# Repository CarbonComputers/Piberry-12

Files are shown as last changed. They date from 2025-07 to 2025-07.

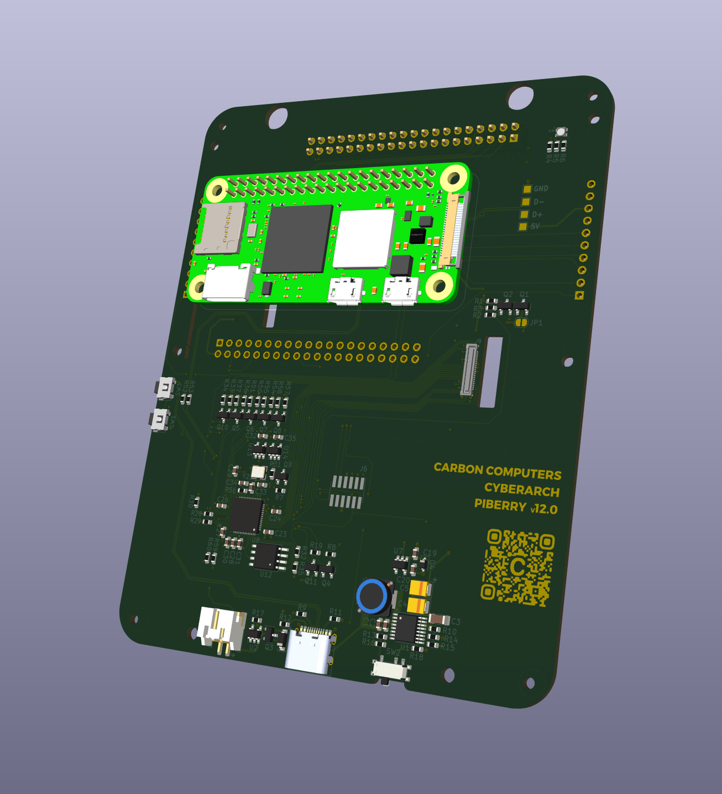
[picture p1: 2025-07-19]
Images/Piberry 12 3D Render bk.png

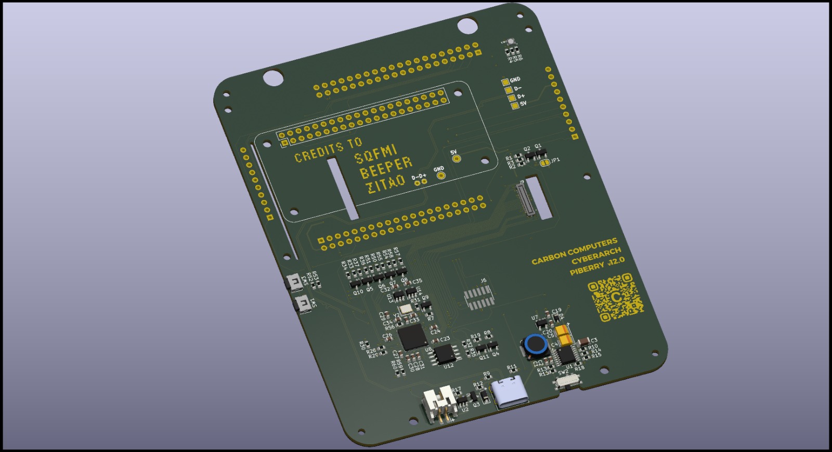
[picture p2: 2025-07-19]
Images/Piberry 12 hd render bk.jpeg

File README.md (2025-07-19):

## PiBerry v12 – Final Iteration

**PiBerry v12** marks the final and most refined revision of the PiBerry handheld Linux terminal. Designed with both form and function in mind, this version brings together the best elements of previous iterations while introducing a more polished aesthetic, improved usability, and support for premium display hardware.

### 🔧 What's New in v12:

* **Refined Aesthetic Design**
  Complete overhaul of the external design for a cleaner, more modern look. Every detail has been revisited to ensure a visually cohesive and ergonomic form factor.
  Keyboard connectivity is simpler as it's driven via USB instead of I2C, you only have to flash the firmware and install the display drivers.

* **HyperPixel 4.0" Display Support**
  Now compatible with the high-resolution **HyperPixel 4.0" touchscreen**, offering a sharper, more responsive interface for your Linux workflows, tools, and custom interfaces, drivers are baked into Pi OS, and many others.
  Waveshare or other 3.5" displays are still compatible, make sure you use the right 3D file

* **Community & Collaboration**
  This final version wouldn’t have been possible without the support and insights of the amazing open-source and hardware community. Special thanks to all contributors, testers, and developers who offered feedback and improvements throughout the PiBerry journey.

### 🔍 Overview:

* Fully integrated handheld Linux device
* Designed around the Raspberry Pi Zero 2W (possibly a CM4 - with a mini carrier)
* Optimized for penetration testing, system diagnostics, portable dev environments, and retro computing/ gaming
* Runs your choice of Linux (Kali, Raspberry Pi OS, etc.)
* Powered by an onboard battery with safe shutdown and charging logic
* Support for keyboards, touch navigation, and peripheral integration with the BBQ20

---

PiBerry v12 is a culmination of passion, learning, and iteration — a celebration of community-powered hardware.

We hope you enjoy building and using it as much as we enjoyed bringing it to life.

Get yours or find out more about the latest builds at [Carbon Computers](https://carboncomputers.us)

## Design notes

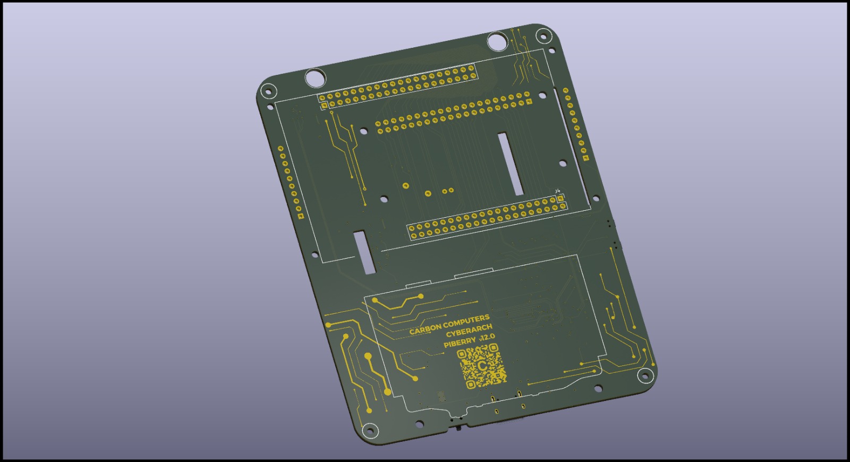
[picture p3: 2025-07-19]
Images/Piberry 12 hd render fr.jpeg

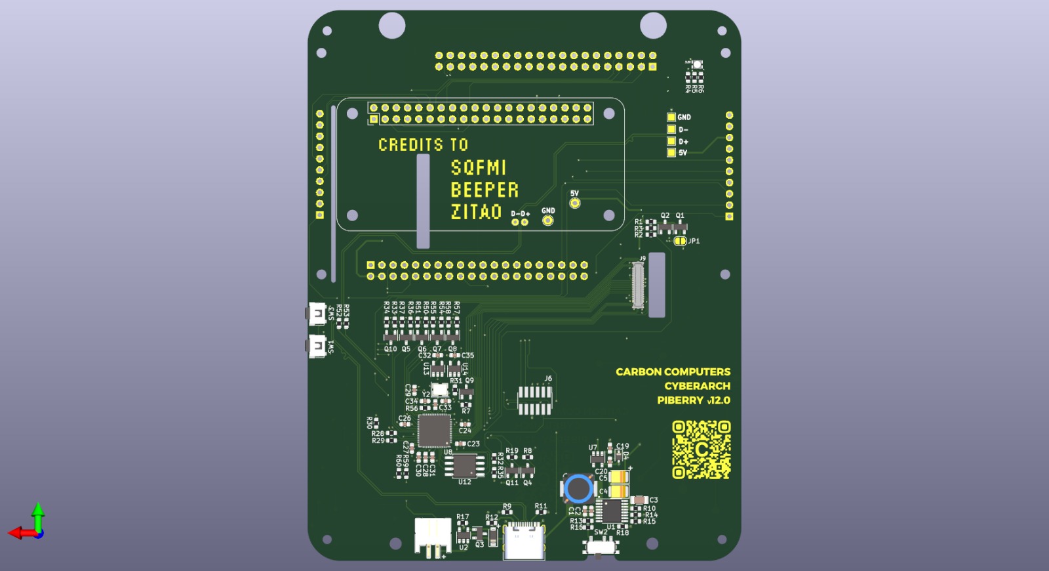
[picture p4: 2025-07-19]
Images/Piberry 12 hd render fl bk.jpeg

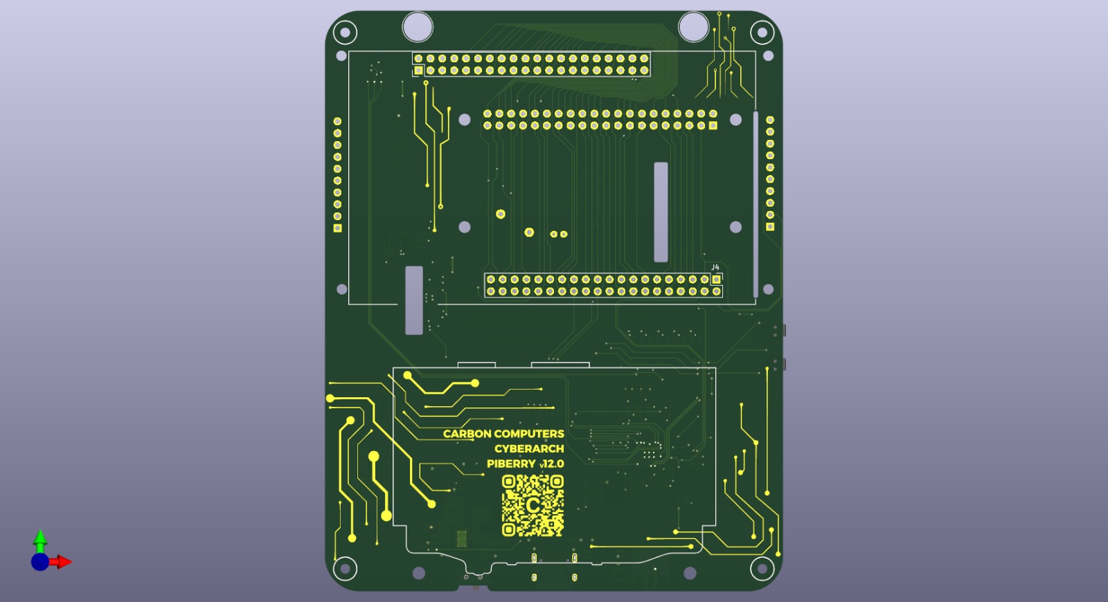
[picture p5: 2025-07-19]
Images/Piberry 12 hd render fl fr.jpeg

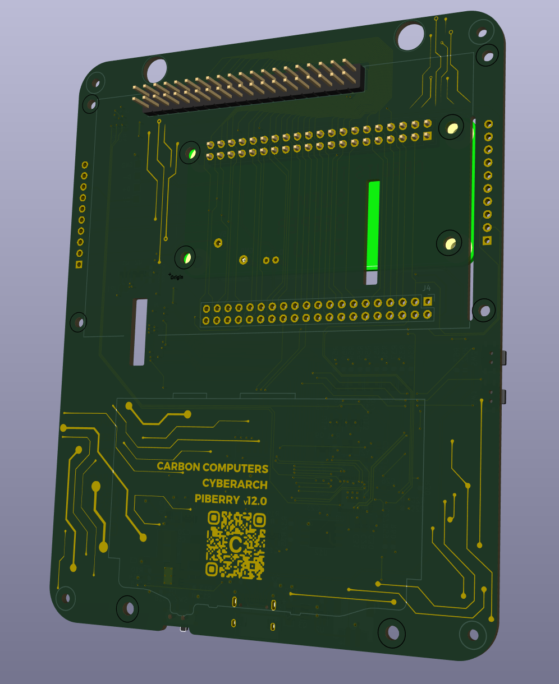
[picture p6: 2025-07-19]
Images/Piberry 12 3D Render fr.png

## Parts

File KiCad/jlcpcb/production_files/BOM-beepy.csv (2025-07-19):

Comment | Designator | Footprint | LCSC
Notification LED | D1 | FM-B2020RGBA-HG | C108793
D_Schottky_Small | D4 | D_SOD-323 | C114023
22uF | C3 | C_1206_3216Metric | C12891
100uF | C4,C5 | CP_EIA-3528-15_AVX-H | C129289
100nF | C2,C23,C24,C25,C26,C27,C29,C30,C32,C35 | C_0603_1608Metric | C14663
1uF | C28,C31 | C_0603_1608Metric | C15849
USB_C_Receptacle_USB2.0 | J7 | USB_C_Receptacle_HRO_TYPE-C-31-M-12 | C165948
RP2040 | U8 | QFN-56-1EP_7x7mm_P0.4mm_EP5.6x5.6mm | C2040
AO3400A | Q10,Q11,Q5,Q6,Q7,Q8,Q9 | SOT-23 | C20917
1K | R32,R56 | R_0603_1608Metric | C21190
100 | R5,R6 | R_0603_1608Metric | C22775
10 | R7 | R_0603_1608Metric | C22859
1M | R15 | R_0603_1608Metric | C22935
220K | R14 | R_0603_1608Metric | C22961
220 | R4 | R_0603_1608Metric | C22962
2M | R10,R13 | R_0603_1608Metric | C22976
330 | R2 | R_0603_1608Metric | C23138
360K | R16 | R_0603_1608Metric | C23146
4.7K | R28,R29 | R_0603_1608Metric | C23162
5.1K | R11,R9 | R_0603_1608Metric | C23186
ME6212C18M5G | U13 | SOT-23-5 | C236669
100K | R12,R18,R59,R60 | R_0603_1608Metric | C25803
10K | R1,R17,R19,R3,R30,R31,R33,R34,R35,R36,R37,R50,R51,R54,R55,R57,R58,R8 | R_0603_1608Metric | C25804
XYDBPCNANF-12MHZ | Y2 | Crystal_SMD_3225-4Pin_3.2x2.5mm | C284155
SI2301 | Q1,Q3 | SOT-23 | C2891731
Battery | J8 | JST_PH_S2B-PH-SM4-TB_1x02-1MP_P2.00mm_Horizontal | C295747
12pF | C33,C34 | C_0603_1608Metric | C38523
27R | R52,R53 | R_0603_1608Metric | C403464
BM20B_0.8_-40DS-0.4V_51_ | J9 | HRS_BM20B_0.8_-40DS-0.4V_51_ | C424543
ME6212C28M5G | U14 | SOT-23-5 | C427596
6.8uH/4A | L1 | L_Bourns_SRP7028A_7.3x6.6mm | C497879
AP2112K-3.3 | U7 | SOT-23-5 | C51118
Header 1 | J1,J3 | PinHeader_1x10_P2.54mm_Vertical | C57369
B5819W | D2 | D_SOD-123 | C64885
TP4054 | U2 | SOT-23-5 | C668215
W25Q32JVSSIQ | U12 | SSOP-8_5.25x5.24mm_P1.27mm | C82344
S8050 | Q2,Q4 | SOT-23 | C916390
ON/OFF | SW2 | SW_SPDT_PCM12 | C963206
SW_DIP_x02 | SW1,SW3 | GT-TC018X | C963235
10uF | C1,C19,C20 | C_0603_1608Metric | C96446
TPS61030 | U1 | HTSSOP-16-1EP_4.4x5mm_P0.65mm_EP3.4x5mm_Mask2.46x2.31mm_ThermalVias | C9842
RPi_GPIO | J2 | PinHeader_2x20_P2.54mm_Vertical

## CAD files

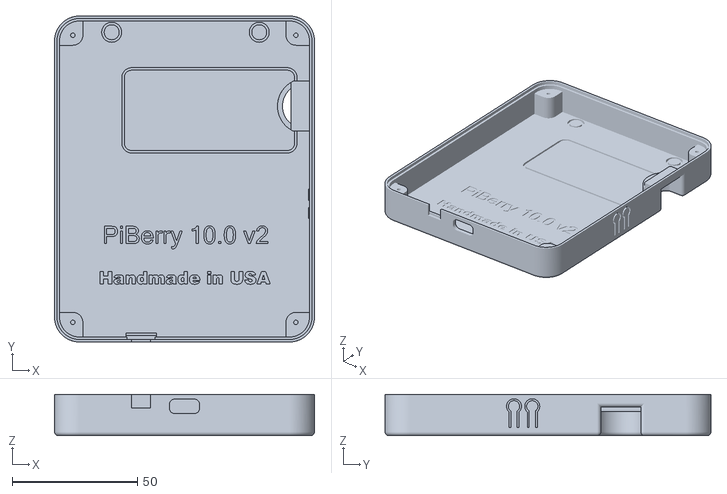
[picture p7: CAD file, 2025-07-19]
3D STL/PiBerry_10.0_v2_retro_STL_STP/PiBerry_10.0_v2_lower_part_rev2.stl
104.0 x 130.4 x 16.5

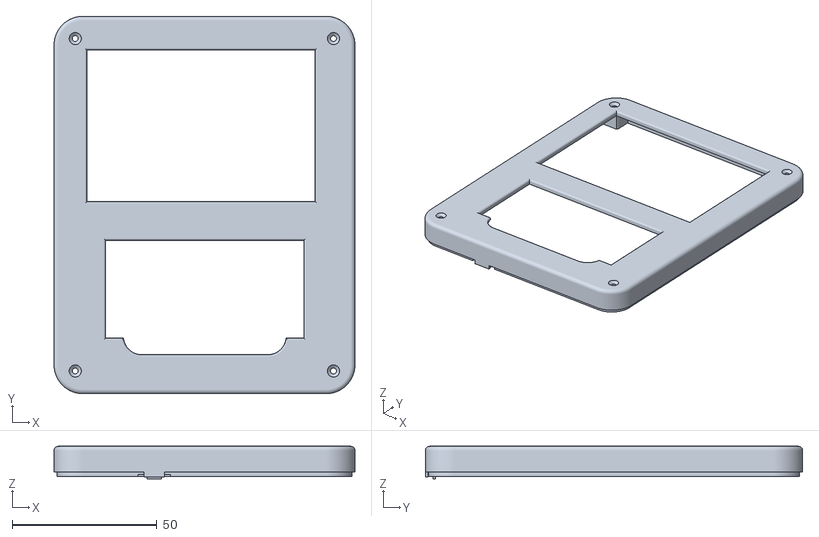
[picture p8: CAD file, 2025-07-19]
3D STL/PiBerry_10.0_v2_simple_STL_STP/PiBerry_10.0_v2_simple_upper_part.stl
104.0 x 130.4 x 11.2

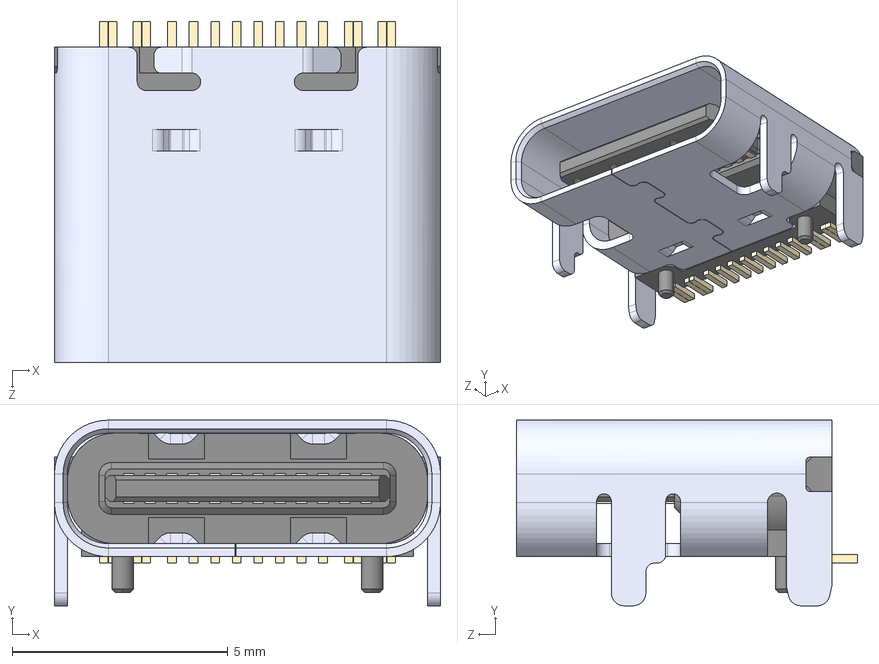
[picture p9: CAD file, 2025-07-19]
KiCad/Step File/TYPE-C-31-M-12--3DModel-STEP-56544.STEP
8.94 x 4.30 x 7.90 mm

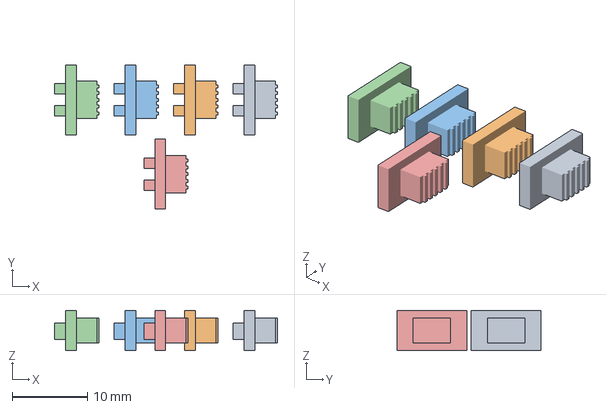
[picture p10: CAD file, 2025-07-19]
3D STL/PiBerry_10.0_v2_retro_STL_STP/sliding_swtich_rev1.3mf
29.7 x 19.2 x 5.35 mm
sliding_swtich_rev1.stl x 5

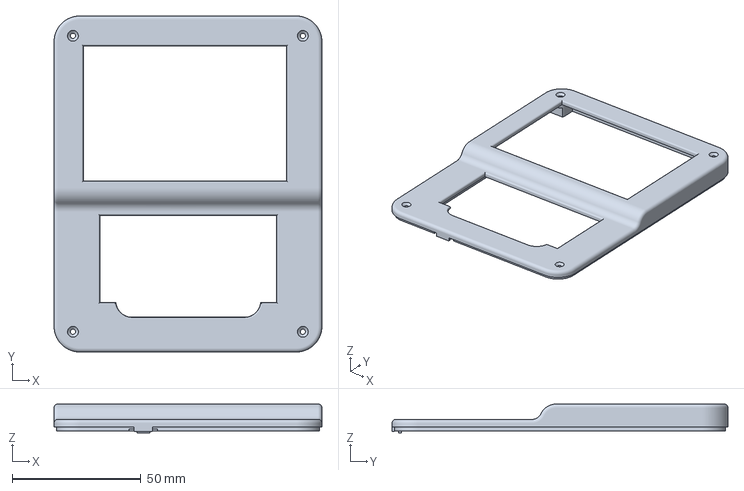
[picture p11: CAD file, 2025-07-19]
3D STL/PiBerry_10.0_v2_retro_STL_STP/PiBerry_10.0_v2_retro_upper_part_rev1.3mf
104.0 x 130.4 x 11.2 mm

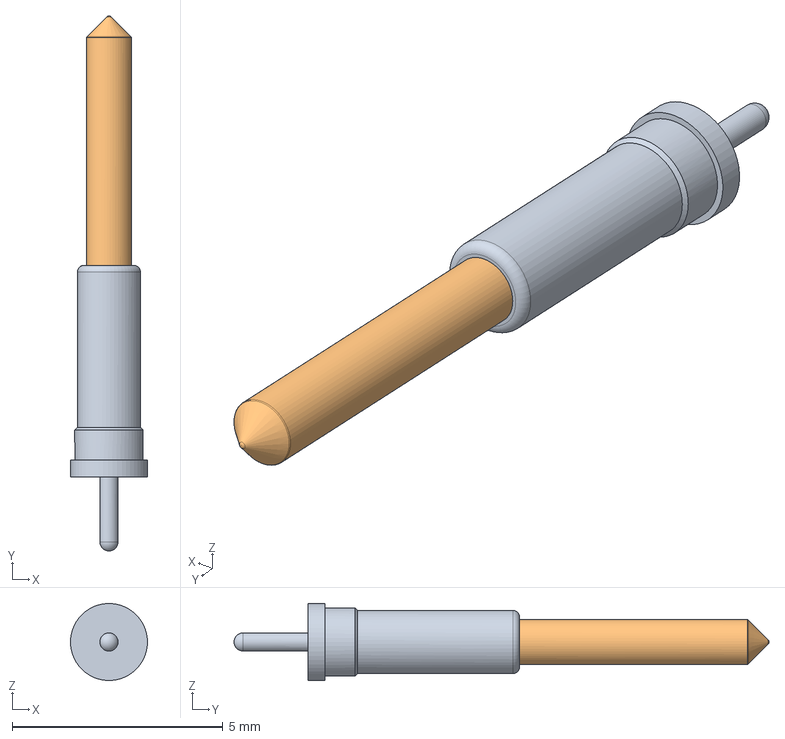
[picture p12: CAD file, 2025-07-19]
KiCad/Step File/pogopin.step
1.83 x 12.7 x 1.83 mm

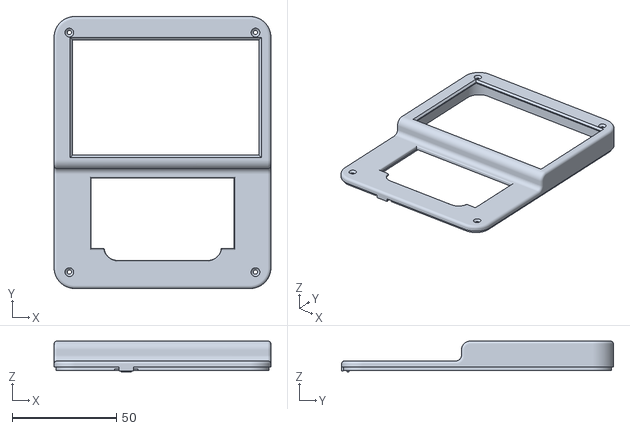
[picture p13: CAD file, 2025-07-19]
3D STL/PiBerry_10.0_v2_retro_STL_STP/PiBerry_12_v1_HyperPixel_upper_part_v1.stl
104.0 x 130.4 x 14.8

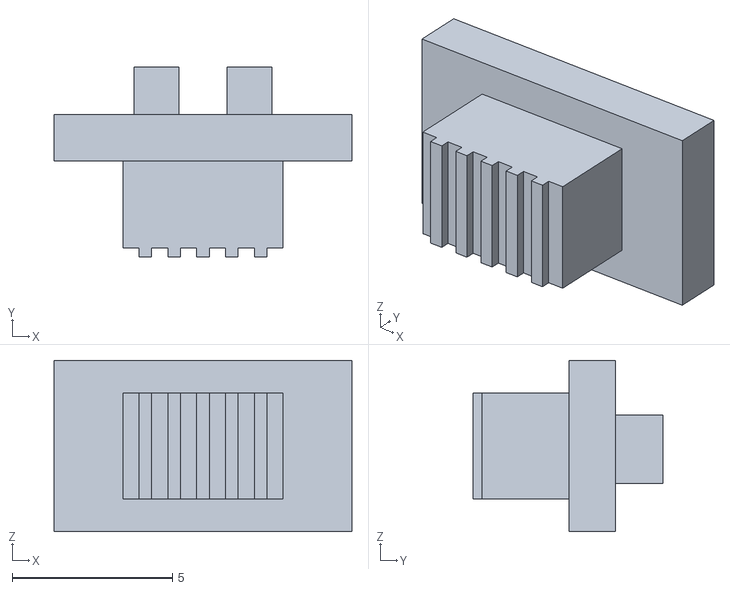
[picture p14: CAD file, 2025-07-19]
3D STL/PiBerry_10.0_v2_simple_STL_STP/sliding_switch_rev1.stl
9.30 x 5.93 x 5.35

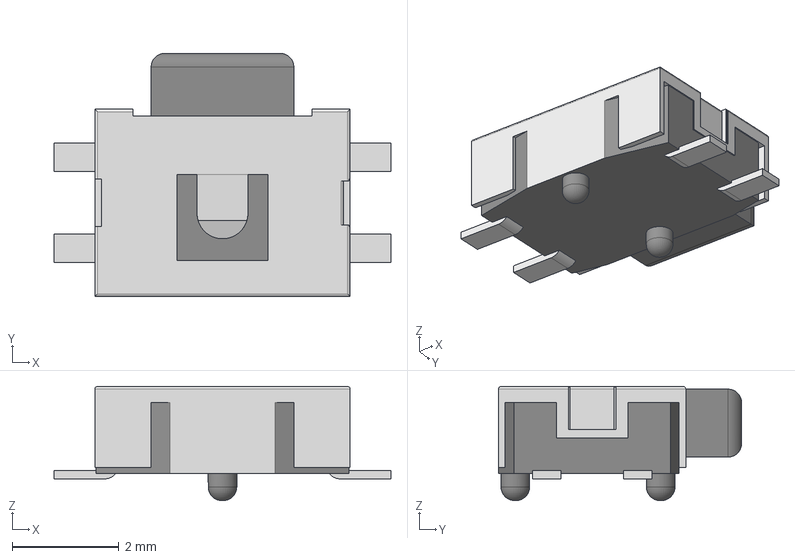
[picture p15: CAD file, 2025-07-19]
KiCad/Step File/YD-3414 - Side SMD Switch .stp
6.30 x 4.55 x 2.13 mm

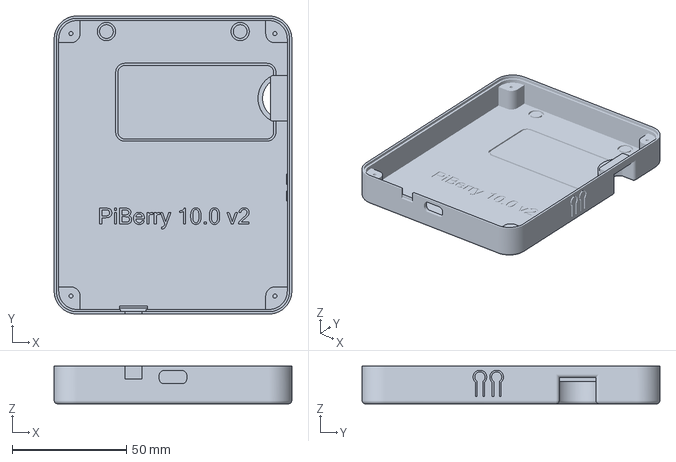
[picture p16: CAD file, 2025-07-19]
3D STL/PiBerry_10.0_v2_retro_STL_STP/PiBerry_10.0_v2_retro_lower_part_rev1.3mf
104.0 x 130.4 x 16.5 mm

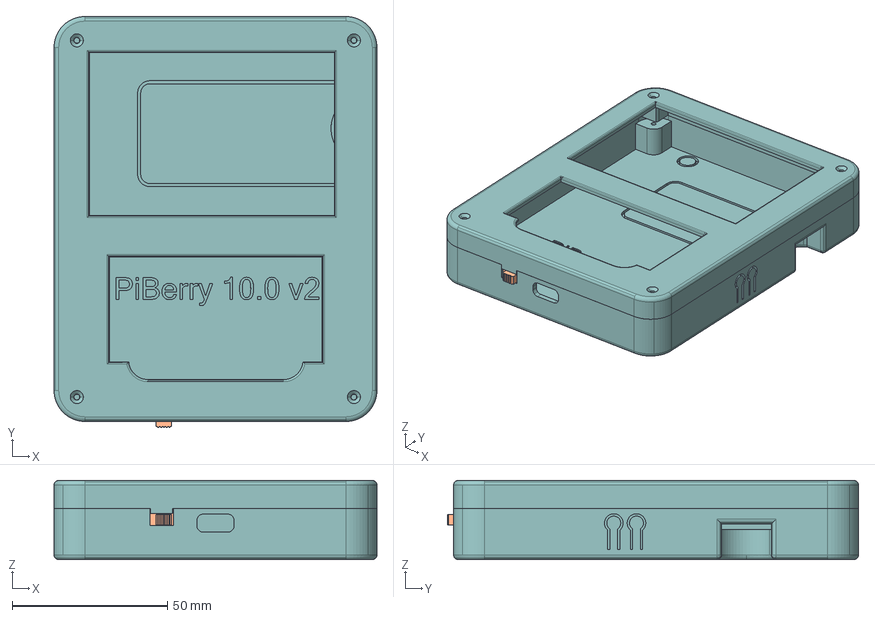
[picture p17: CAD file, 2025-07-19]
3D STL/PiBerry_10.0_v2_simple_STL_STP/PiBerry_10.0_v2_simple.stp
104.0 x 132.3 x 25.4 mm
PiBerry_10.0_v2_simple_upper_part
PiBerry_10.0_v2_simple_lower_part
sliding_switch

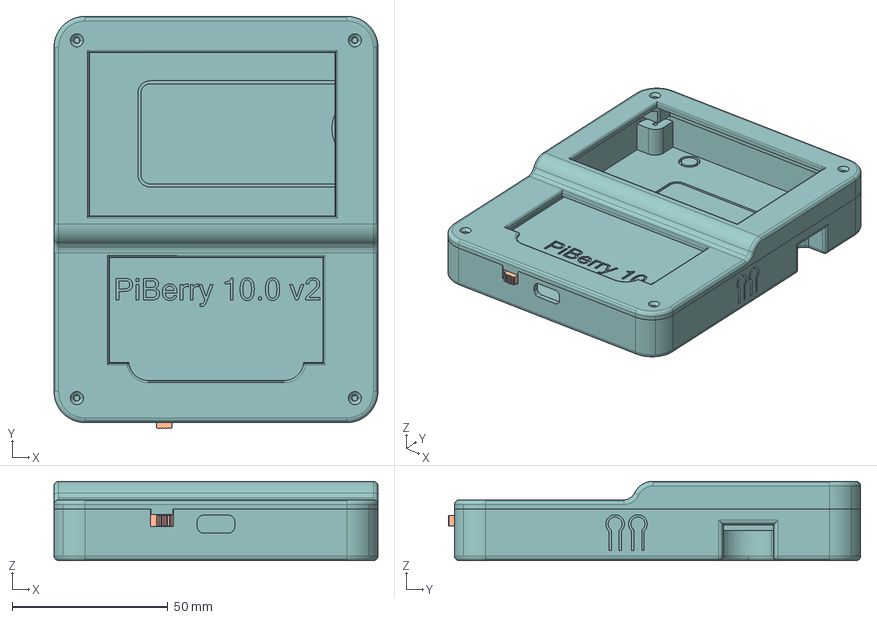
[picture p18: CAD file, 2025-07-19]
3D STL/PiBerry_10.0_v2_retro_STL_STP/PiBerry_10.0_v2_retro_rev1.stp
104.0 x 132.3 x 25.4 mm
PiBerry_10.0_v2_retro_upper_part_rev1
PiBerry_10.0_v2_retro_lower_part_rev1
sliding_switch_rev1

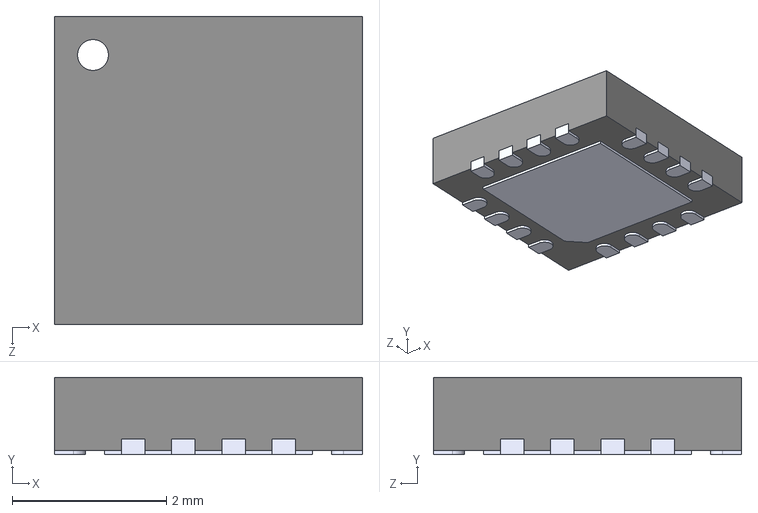
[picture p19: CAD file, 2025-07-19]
KiCad/Step File/TPS61090RSAR.step
4.00 x 1.00 x 4.00 mm

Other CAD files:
3D STL/PiBerry_10.0_v2_simple_STL_STP/PiBerry_10.0_v2_simple_lower_part.stl
3D STL/PiBerry_10.0_v2_retro_STL_STP/PiBerry_10.0_v2_retro_lower_part_rev1.stl
3D STL/PiBerry_10.0_v2_retro_STL_STP/PiBerry_10.0_v2_retro_upper_part_rev1.stl
3D STL/PiBerry_10.0_v2_retro_STL_STP/sliding_swtich_rev1.stl

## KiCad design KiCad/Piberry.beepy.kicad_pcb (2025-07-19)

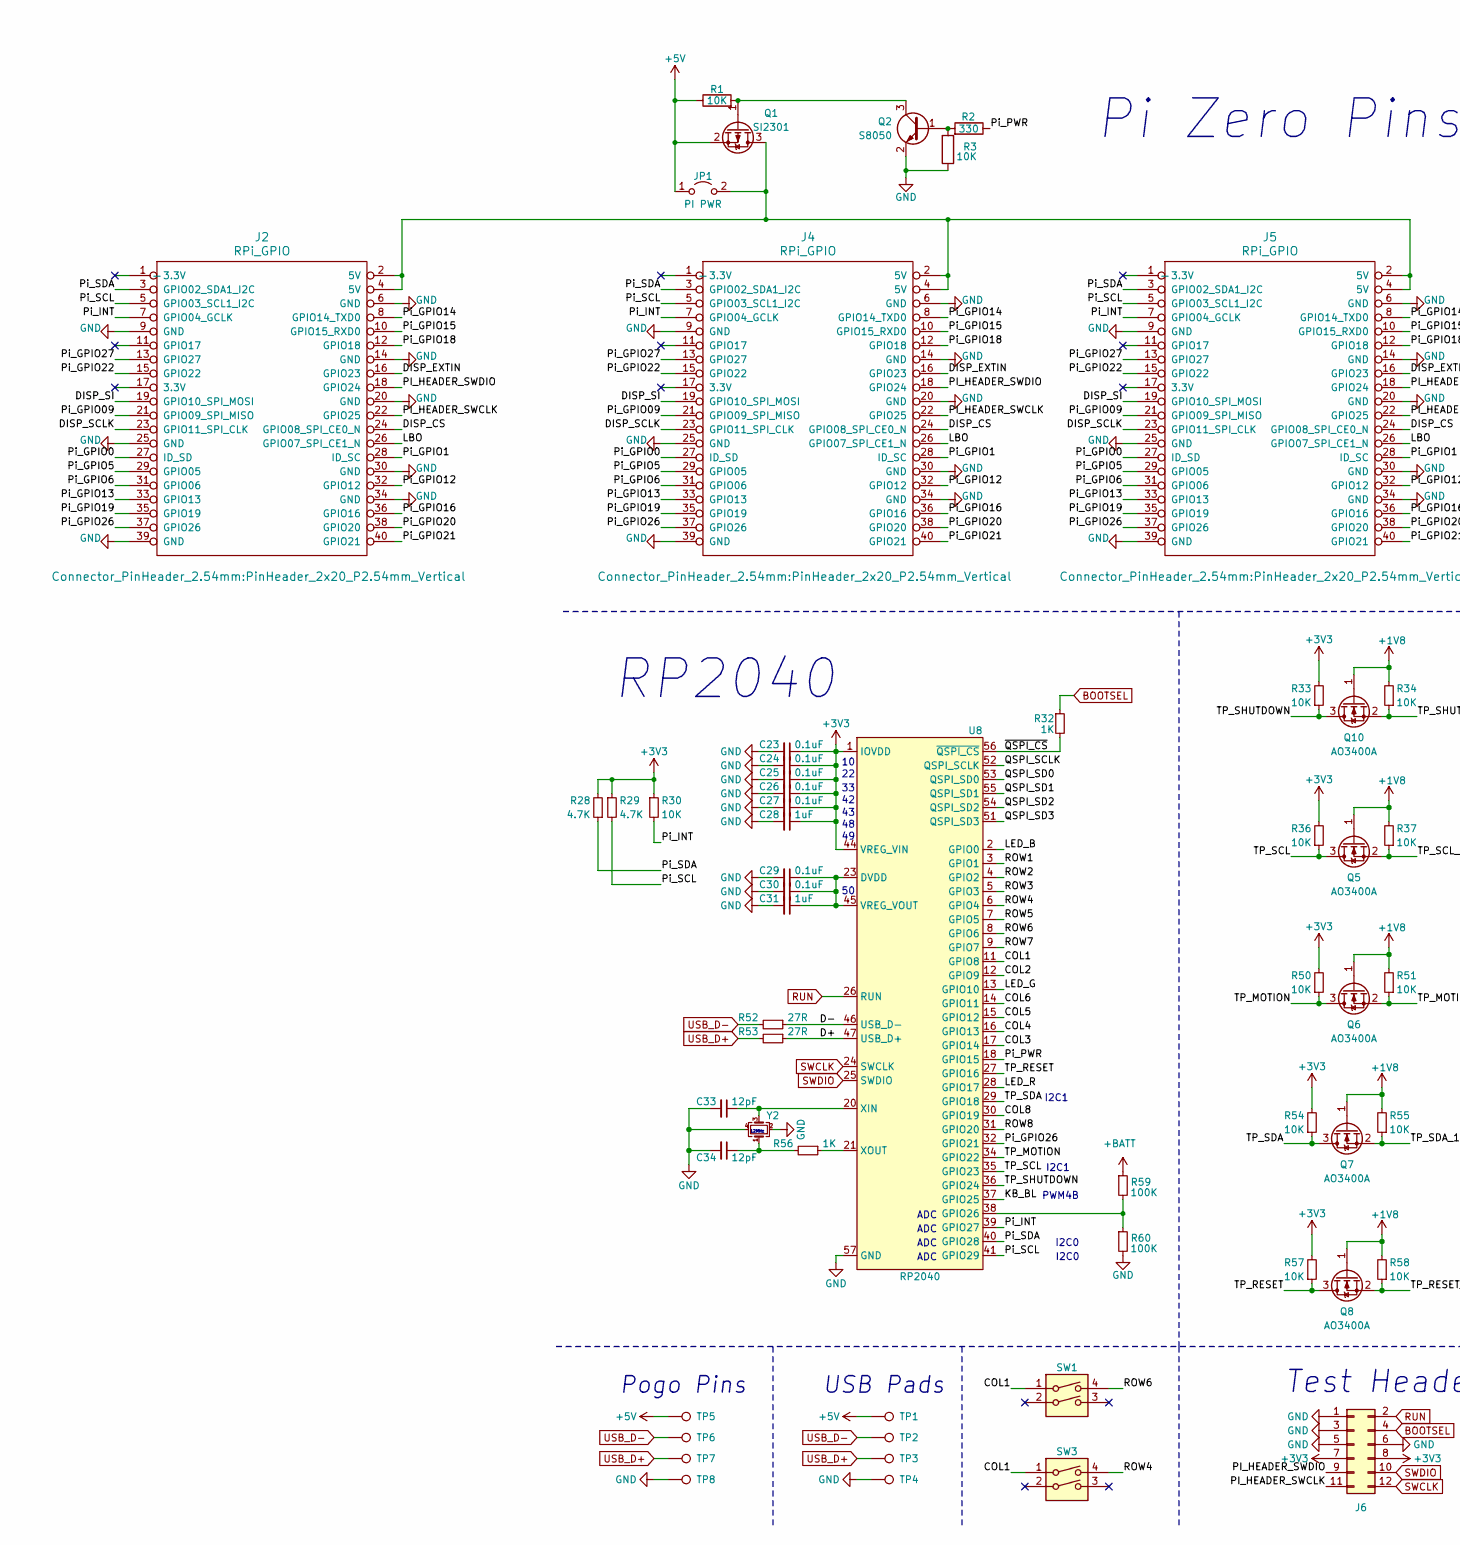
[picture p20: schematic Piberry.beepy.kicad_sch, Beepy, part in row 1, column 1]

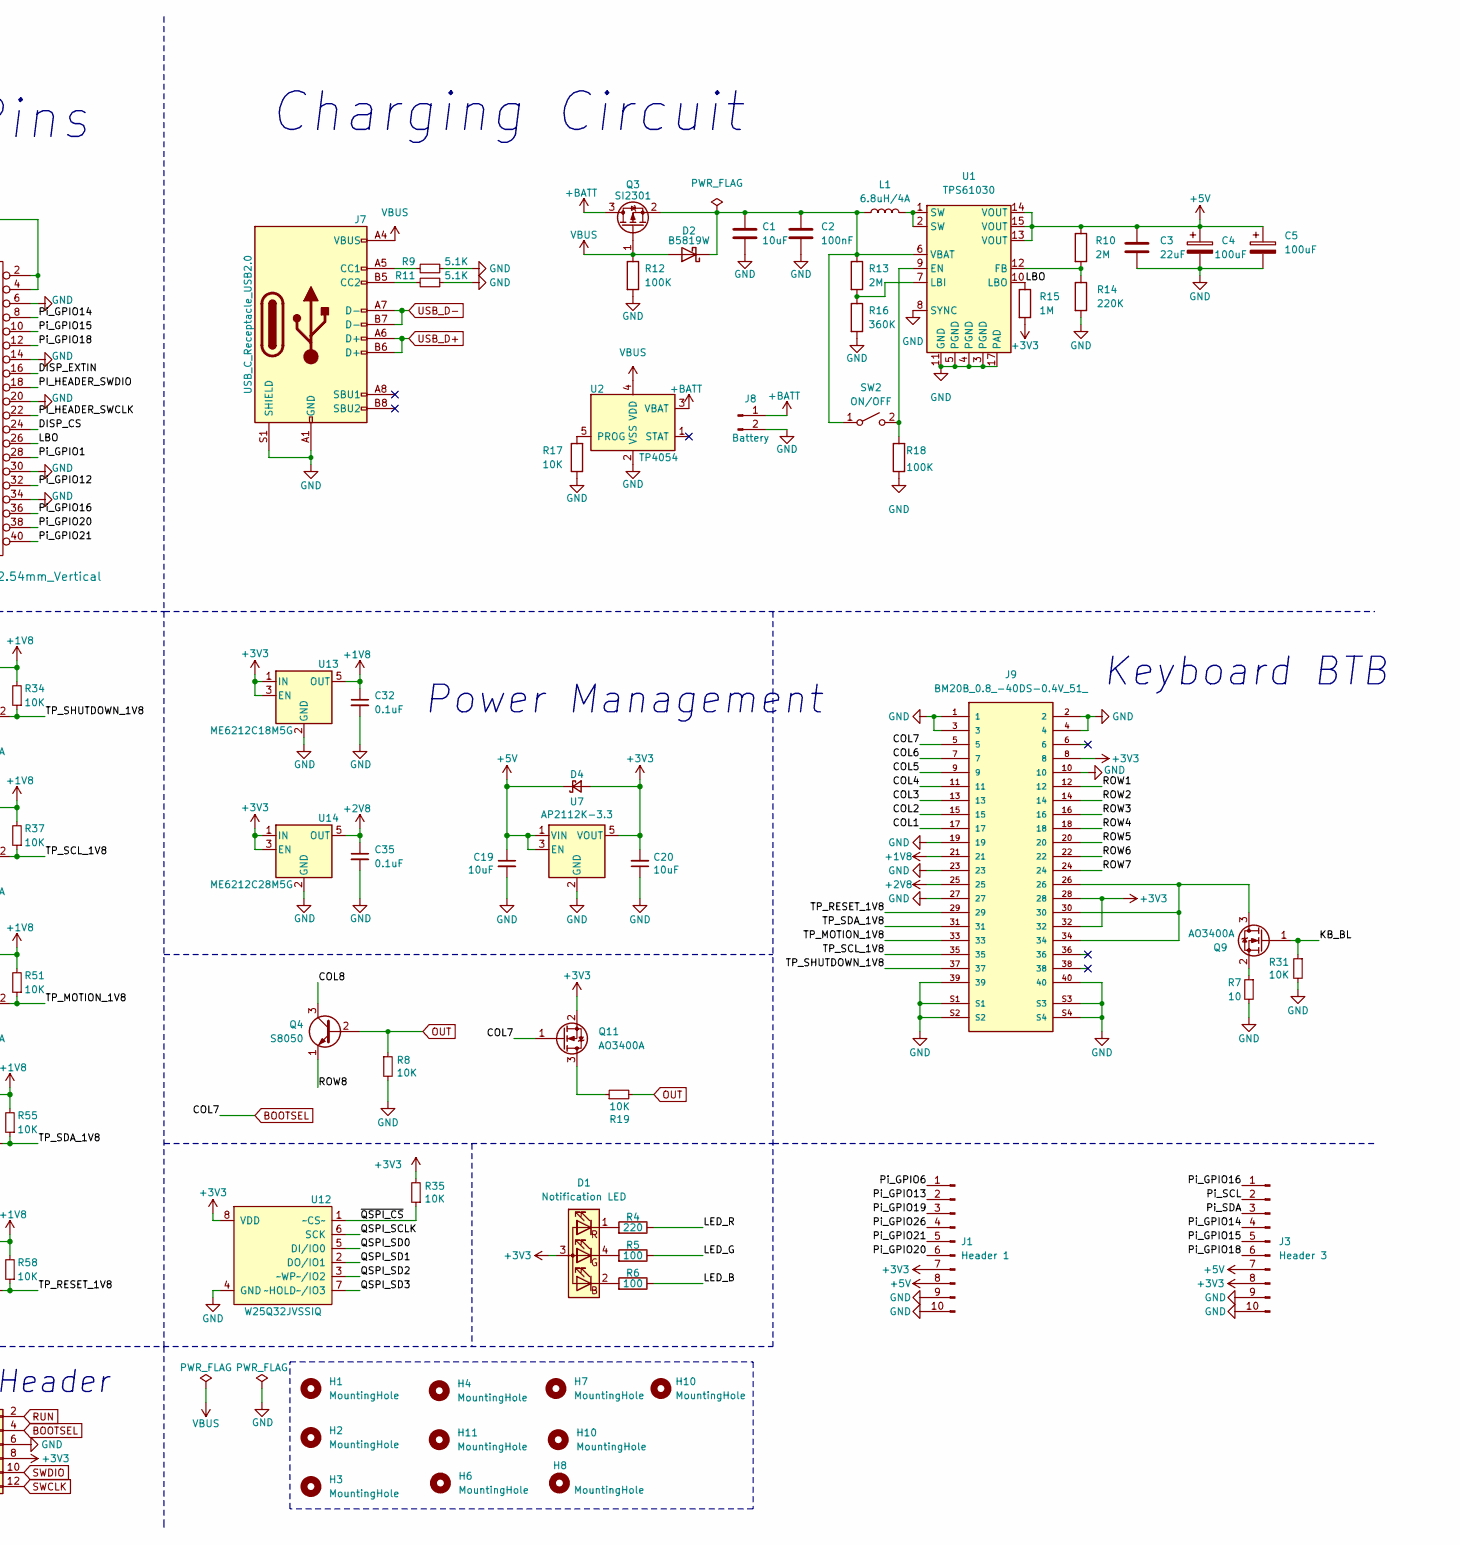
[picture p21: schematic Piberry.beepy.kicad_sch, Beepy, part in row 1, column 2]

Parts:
C1, C19, C20: 10uF; C_0603_1608Metric; LCSC C96446
C2: 100nF; C_0603_1608Metric; LCSC C14663
C3: 22uF; C_1206_3216Metric; LCSC C12891
C4, C5: 100uF; CP_EIA-3528-15_AVX-H; LCSC C129289
C23, C24, C25, C26, C27, C29, C30, C32, C35: 0.1uF; C_0603_1608Metric; LCSC C14663
C28, C31: 1uF; C_0603_1608Metric; LCSC C15849
C33, C34: 12pF; C_0603_1608Metric; LCSC C38523
D1: Notification LED; FM-B2020RGBA-HG; LCSC C108793
D2: B5819W; D_SOD-123; LCSC C64885
D4: D_Schottky_Small; D_SOD-323; LCSC C114023
H1, H4, H7, H10: MountingHole; MountingHole_2.2mm_M2
H2, H3, H6, H11: MountingHole; MountingHole_2.5mm
H8: MountingHole; MountingHole_2.7mm_M2.5
J1: Header 1; PinHeader_1x10_P2.54mm_Vertical; LCSC C57369
J2, J4, J5: RPi_GPIO; PinHeader_2x20_P2.54mm_Vertical
J3: Header 3; PinHeader_1x10_P2.54mm_Vertical; LCSC C57369
J6: PRG_HEADER; PinHeader_2x06_P1.27mm_Vertical_SMD
J7: USB_C_Receptacle_USB2.0; USB_C_Receptacle_HRO_TYPE-C-31-M-12; LCSC C165948
J8: Battery; JST_PH_S2B-PH-SM4-TB_1x02-1MP_P2.00mm_Horizontal; LCSC C295747
J9: BM20B_0.8_-40DS-0.4V_51_; HRS_BM20B_0.8_-40DS-0.4V_51_; LCSC C424543
JP1: PI PWR; SolderJumper-2_P1.3mm_Open_RoundedPad1.0x1.5mm
L1: 6.8uH/4A; L_Bourns_SRP7028A_7.3x6.6mm; LCSC C497879
Q1, Q3: SI2301; SOT-23; LCSC C2891731
Q2, Q4: S8050; SOT-23; LCSC C916390
Q5, Q6, Q7, Q8, Q9, Q10, Q11: AO3400A; SOT-23; LCSC C20917
R1, R3, R8, R17, R19, R30, R31, R33, R34, R35, R36, R37, R50, R51, R54, R55, R57, R58: 10K; R_0603_1608Metric; LCSC C25804
R2: 330; R_0603_1608Metric; LCSC C23138
R4: 220; R_0603_1608Metric; LCSC C22962
R5, R6: 100; R_0603_1608Metric; LCSC C22775
R7: 10; R_0603_1608Metric; LCSC C22859
R9, R11: 5.1K; R_0603_1608Metric; LCSC C23186
R10, R13: 2M; R_0603_1608Metric; LCSC C22976
R12, R18, R59, R60: 100K; R_0603_1608Metric; LCSC C25803
R14: 220K; R_0603_1608Metric; LCSC C22961
R15: 1M; R_0603_1608Metric; LCSC C22935
R16: 360K; R_0603_1608Metric; LCSC C23146
R28, R29: 4.7K; R_0603_1608Metric; LCSC C23162
R32, R56: 1K; R_0603_1608Metric; LCSC C21190
R52, R53: 27R; R_0603_1608Metric; LCSC C403464
SW1, SW3: SW_DIP_x02; GT-TC018X; LCSC C963235
SW2: ON/OFF; SW_SPDT_PCM12; LCSC C963206
TP1, TP2, TP3, TP4: TestPoint; TestPoint_Pad_1.5x1.5mm
TP5, TP8: TestPoint; TestPoint_THTPad_D2.0mm_Drill1.0mm
TP6, TP7: TestPoint; TestPoint_THTPad_D1.5mm_Drill0.7mm
U1: TPS61030; HTSSOP-16-1EP_4.4x5mm_P0.65mm_EP3.4x5mm_Mask2.46x2.31mm_The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; LCSC C9842
U2: TP4054; SOT-23-5; LCSC C668215
U7: AP2112K-3.3; SOT-23-5; LCSC C51118
U8: RP2040; QFN-56-1EP_7x7mm_P0.4mm_EP5.6x5.6mm; LCSC C2040
U12: W25Q32JVSSIQ; SSOP-8_5.25x5.24mm_P1.27mm; LCSC C82344
U13: ME6212C18M5G; SOT-23-5; LCSC C236669
U14: ME6212C28M5G; SOT-23-5; LCSC C427596
Y2: XYDBPCNANF-12MHZ; Crystal_SMD_3225-4Pin_3.2x2.5mm; LCSC C284155

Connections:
+1V8: C32.1, J9.21, Q5.1 (G), Q6.1 (G), Q7.1 (G), Q8.1 (G), Q10.1 (G), R34.2, R37.2, R51.2, R55.2, R58.2, U13.5 (OUT)
+2V8: C35.1, J9.25, U14.5 (OUT)
+3V3: C20.2, C23.1, C24.1, C25.1, C26.1, C27.1, C28.1, D1.3 (A), D4.2 (A), J1.7, J3.8, J6.7, J6.8, J9.8, J9.28, J9.32, Q11.2 (S), R15.2, R28.2, R29.1, R30.1, R33.2, R35.2, R36.2, R50.2, R54.2, R57.2, U7.5 (VOUT), U8.1 (IOVDD), U8.10 (IOVDD), U8.22 (IOVDD), U8.33 (IOVDD), U8.42 (IOVDD), U8.43 (ADC_AVDD), U8.44 (VREG_VIN), U8.48 (USB_VDD), U8.49 (IOVDD), U12.8 (VDD), U13.1 (IN), U13.3 (EN), U14.1 (IN), U14.3 (EN)
+5V: C3.1, C4.1, C5.1, C19.1, D4.1 (K), J1.8, J3.7, JP1.1 (A), Q1.2 (S), R1.1, R10.1, TP1.1, TP5.1, U1.13 (VOUT), U1.14 (VOUT), U1.15 (VOUT), U7.1 (VIN), U7.3 (EN)
+BATT: J8.1, Q3.3 (D), R59.1, U2.3 (VBAT)
/COL1: J9.17, SW1.1, SW3.1, U8.11 (GPIO8)
/COL2: J9.15, U8.12 (GPIO9)
/COL3: J9.13, U8.17 (GPIO14)
/COL4: J9.11, U8.16 (GPIO13)
/COL5: J9.9, U8.15 (GPIO12)
/COL6: J9.7, U8.14 (GPIO11)
/COL8: Q4.3 (C), U8.30 (GPIO19)
/D+: R53.1, U8.47 (USB_D+)
/D-: R52.1, U8.46 (USB_D-)
/DISP_CS: J2.24 (GPIO08_SPI_CE0_N), J4.24 (GPIO08_SPI_CE0_N), J5.24 (GPIO08_SPI_CE0_N)
/DISP_EXTIN: J2.16 (GPIO23), J4.16 (GPIO23), J5.16 (GPIO23)
/DISP_SCLK: J2.23 (GPIO11_SPI_CLK), J4.23 (GPIO11_SPI_CLK), J5.23 (GPIO11_SPI_CLK)
/DISP_SI: J2.19 (GPIO10_SPI_MOSI), J4.19 (GPIO10_SPI_MOSI), J5.19 (GPIO10_SPI_MOSI)
/KB_BL: Q9.1 (G), R31.1, U8.37 (GPIO25)
/LBO: J2.26 (GPIO07_SPI_CE1_N), J4.26 (GPIO07_SPI_CE1_N), J5.26 (GPIO07_SPI_CE1_N), R15.1, U1.10 (LBO)
/LED_B: R6.1, U8.2 (GPIO0)
/LED_G: R5.1, U8.13 (GPIO10)
/LED_R: R4.1, U8.28 (GPIO17)
/PI_HEADER_SWCLK: J2.22 (GPIO25), J4.22 (GPIO25), J5.22 (GPIO25), J6.11
/PI_HEADER_SWDIO: J2.18 (GPIO24), J4.18 (GPIO24), J5.18 (GPIO24), J6.9
/Pi_GPIO0: J2.27 (ID_SD), J4.27 (ID_SD), J5.27 (ID_SD)
/Pi_GPIO1: J2.28 (ID_SC), J4.28 (ID_SC), J5.28 (ID_SC)
/Pi_GPIO5: J2.29 (GPIO05), J4.29 (GPIO05), J5.29 (GPIO05)
/Pi_GPIO6: J1.1, J2.31 (GPIO06), J4.31 (GPIO06), J5.31 (GPIO06)
/Pi_GPIO09: J2.21 (GPIO09_SPI_MISO), J4.21 (GPIO09_SPI_MISO), J5.21 (GPIO09_SPI_MISO)
/Pi_GPIO12: J2.32 (GPIO12), J4.32 (GPIO12), J5.32 (GPIO12)
/Pi_GPIO13: J1.2, J2.33 (GPIO13), J4.33 (GPIO13), J5.33 (GPIO13)
/Pi_GPIO14: J2.8 (GPIO14_TXD0), J3.4, J4.8 (GPIO14_TXD0), J5.8 (GPIO14_TXD0)
/Pi_GPIO15: J2.10 (GPIO15_RXD0), J3.5, J4.10 (GPIO15_RXD0), J5.10 (GPIO15_RXD0)
/Pi_GPIO16: J2.36 (GPIO16), J3.1, J4.36 (GPIO16), J5.36 (GPIO16)
/Pi_GPIO18: J2.12 (GPIO18), J3.6, J4.12 (GPIO18), J5.12 (GPIO18)
/Pi_GPIO19: J1.3, J2.35 (GPIO19), J4.35 (GPIO19), J5.35 (GPIO19)
/Pi_GPIO20: J1.6, J2.38 (GPIO20), J4.38 (GPIO20), J5.38 (GPIO20)
/Pi_GPIO21: J1.5, J2.40 (GPIO21), J4.40 (GPIO21), J5.40 (GPIO21)
/Pi_GPIO22: J2.15 (GPIO22), J4.15 (GPIO22), J5.15 (GPIO22)
/Pi_GPIO26: J1.4, J2.37 (GPIO26), J4.37 (GPIO26), J5.37 (GPIO26), U8.32 (GPIO21)
/Pi_GPIO27: J2.13 (GPIO27), J4.13 (GPIO27), J5.13 (GPIO27)
/Pi_INT: J2.7 (GPIO04_GCLK), J4.7 (GPIO04_GCLK), J5.7 (GPIO04_GCLK), R30.2, U8.39 (GPIO27)
/Pi_PWR: R2.1, U8.18 (GPIO15)
/Pi_SCL: J2.5 (GPIO03_SCL1_I2C), J3.2, J4.5 (GPIO03_SCL1_I2C), J5.5 (GPIO03_SCL1_I2C), R29.2, U8.41 (GPIO29)
/Pi_SDA: J2.3 (GPIO02_SDA1_I2C), J3.3, J4.3 (GPIO02_SDA1_I2C), J5.3 (GPIO02_SDA1_I2C), R28.1, U8.40 (GPIO28)
/QSPI_SCLK: U8.52 (QSPI_SCLK), U12.6 (SCK)
/QSPI_SD0: U8.53 (QSPI_SD0), U12.5 (DI/IO0)
/QSPI_SD1: U8.55 (QSPI_SD1), U12.2 (DO/IO1)
/QSPI_SD2: U8.54 (QSPI_SD2), U12.3 (~WP~/IO2)
/QSPI_SD3: U8.51 (QSPI_SD3), U12.7 (~HOLD~/IO3)
/ROW1: J9.12, U8.3 (GPIO1)
/ROW2: J9.14, U8.4 (GPIO2)
/ROW3: J9.16, U8.5 (GPIO3)
/ROW4: J9.18, SW3.4, U8.6 (GPIO4)
/ROW5: J9.20, U8.7 (GPIO5)
/ROW6: J9.22, SW1.4, U8.8 (GPIO6)
/ROW7: J9.24, U8.9 (GPIO7)
/ROW8: Q4.1 (E), U8.31 (GPIO20)
/TP_MOTION: Q6.3 (D), R50.1, U8.34 (GPIO22)
/TP_MOTION_1V8: J9.33, Q6.2 (S), R51.1
/TP_RESET: Q8.3 (D), R57.1, U8.27 (GPIO16)
/TP_RESET_1V8: J9.29, Q8.2 (S), R58.1
/TP_SCL: Q5.3 (D), R36.1, U8.35 (GPIO23)
/TP_SCL_1V8: J9.35, Q5.2 (S), R37.1
/TP_SDA: Q7.3 (D), R54.1, U8.29 (GPIO18)
/TP_SDA_1V8: J9.31, Q7.2 (S), R55.1
/TP_SHUTDOWN: Q10.3 (D), R33.1, U8.36 (GPIO24)
/TP_SHUTDOWN_1V8: J9.37, Q10.2 (S), R34.1
/~QSPI_CS: R32.2, R35.1, U8.56 (~QSPI_CS), U12.1 (~CS~)
BOOTSEL: J6.4, J9.5, Q11.1 (G), R32.1
GND: C1.2, C2.2, C3.2, C4.2, C5.2, C19.2, C20.1, C23.2, C24.2, C25.2, C26.2, C27.2, C28.2, C29.2, C30.2, C31.2, C32.2, C33.2, C34.2, C35.2, J1.9, J1.10, J2.6 (GND), J2.9 (GND), J2.14 (GND), J2.20 (GND), J2.25 (GND), J2.30 (GND), J2.34 (GND), J2.39 (GND), J3.9, J3.10, J4.6 (GND), J4.9 (GND), J4.14 (GND), J4.20 (GND), J4.25 (GND), J4.30 (GND), J4.34 (GND), J4.39 (GND), J5.6 (GND), J5.9 (GND), J5.14 (GND), J5.20 (GND), J5.25 (GND), J5.30 (GND), J5.34 (GND), J5.39 (GND), J6.1, J6.3, J6.5, J6.6, J7.A1 (GND), J7.A12 (GND), J7.B1 (GND), J7.B12 (GND), J7.S1 (SHIELD), J8.2, J9.1, J9.2, J9.3, J9.4, J9.10, J9.19, J9.23, J9.27, J9.39, J9.40, J9.S1, J9.S2, J9.S3, J9.S4, Q2.2 (E), R3.1, R7.2, R8.2, R9.1, R11.1, R12.2, R14.2, R16.2, R17.1, R18.1, R31.2, R60.2, TP4.1, TP8.1, U1.3 (PGND), U1.4 (PGND), U1.5 (PGND), U1.8 (SYNC), U1.11 (GND), U1.17 (PAD), U2.2 (VSS), U7.2 (GND), U8.19 (TESTEN), U8.57 (GND), U12.4 (GND), U12.9 (GND), U13.2 (GND), U14.2 (GND), Y2.2, Y2.4
unnamed: C34.1, R56.2, Y2.1
unnamed: D1.2 (BK), R6.2
unnamed: D1.4 (GK), R5.2
unnamed: D1.1 (RK), R4.2
unnamed: C1.1, C2.1, D2.1 (K), L1.1, Q3.2 (S), R13.1, SW2.1 (A), U1.6 (VBAT)
unnamed: J7.A5 (CC1), R9.2
unnamed: J7.B5 (CC2), R11.2
unnamed: J2.2 (5V), J2.4 (5V), J4.2 (5V), J4.4 (5V), J5.2 (5V), J5.4 (5V), JP1.2 (B), Q1.3 (D)
unnamed: L1.2, U1.1 (SW), U1.2 (SW)
unnamed: Q1.1 (G), Q2.3 (C), R1.2
unnamed: Q2.1 (B), R2.2, R3.2
unnamed: J9.26, J9.30, J9.34, Q9.3 (D)
unnamed: Q9.2 (S), R7.1
unnamed: Q11.3 (D), R19.1
unnamed: R18.2, SW2.2 (B), U1.9 (EN)
unnamed: R10.2, R14.1, U1.12 (FB)
unnamed: R13.2, R16.1, U1.7 (LBI)
unnamed: R17.2, U2.5 (PROG)
unnamed: R59.2, R60.1, U8.38 (GPIO26)
unnamed: C29.1, C30.1, C31.1, U8.23 (DVDD), U8.45 (VREG_VOUT), U8.50 (DVDD)
unnamed: C33.1, U8.20 (XIN), Y2.3
unnamed: R56.1, U8.21 (XOUT)
OUT: Q4.2 (B), R8.1, R19.2
RUN: J6.2, U8.26 (RUN)
SWCLK: J6.12, U8.24 (SWCLK)
SWDIO: J6.10, U8.25 (SWDIO)
USB_D+: J7.A6 (D+), J7.B6 (D+), R53.2, TP3.1, TP7.1
USB_D-: J7.A7 (D-), J7.B7 (D-), R52.2, TP2.1, TP6.1
VBUS: D2.2 (A), J7.A4 (VBUS), J7.A9 (VBUS), J7.B4 (VBUS), J7.B9 (VBUS), Q3.1 (G), R12.1, U2.4 (VDD)

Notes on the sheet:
RP2040
USB Pads
I2C1
ADC
Charging Circuit
I2C0
Pi Zero Pins
Test Header
Pogo Pins
PWM4B
Keyboard BTB
Power Management
12MHz

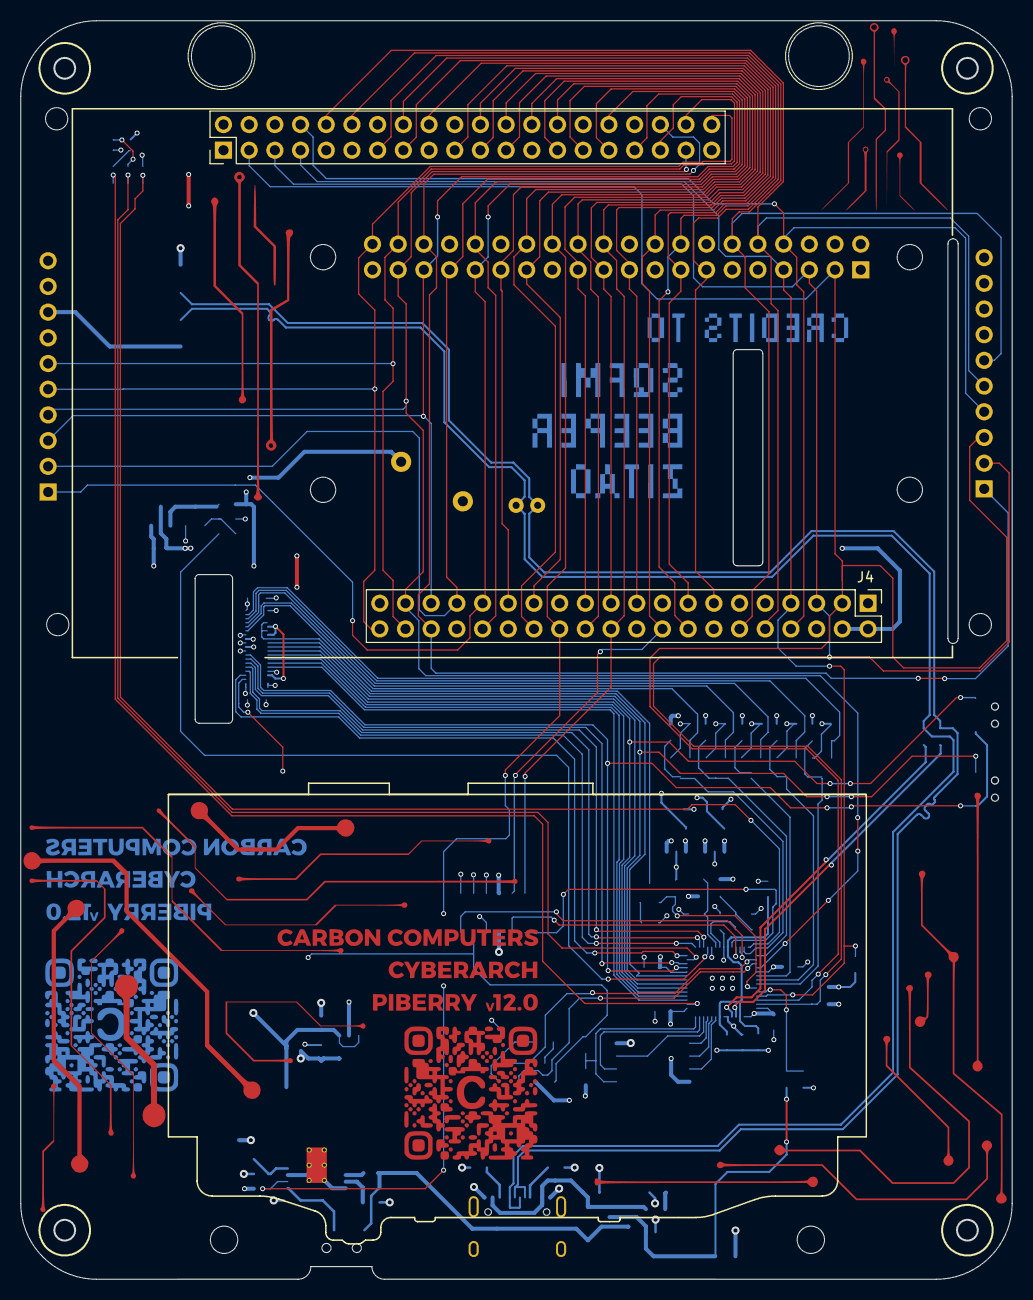
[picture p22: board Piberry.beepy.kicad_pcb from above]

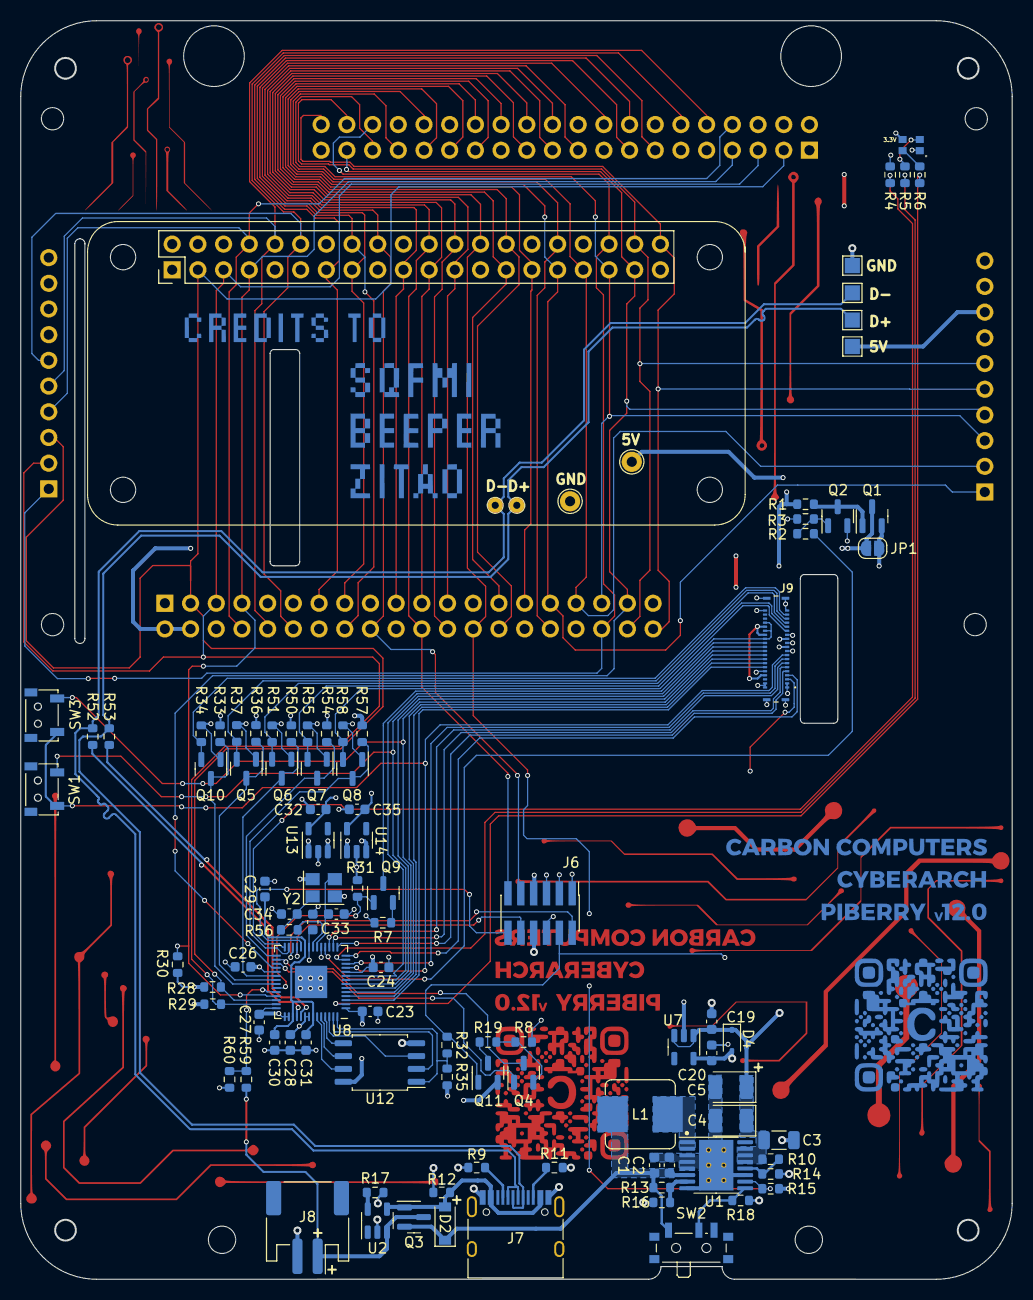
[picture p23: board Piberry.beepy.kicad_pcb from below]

Board: 4 copper layers, 98.0 x 124.4 mm, 114 parts (102 on the bottom side), 101 nets.

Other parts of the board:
H5, H9: MountingHole; MountingHole_2.5mm

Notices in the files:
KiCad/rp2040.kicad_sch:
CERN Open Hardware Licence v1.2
